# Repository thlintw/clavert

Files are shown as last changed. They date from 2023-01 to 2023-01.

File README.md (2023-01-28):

# Clavert Keyboard

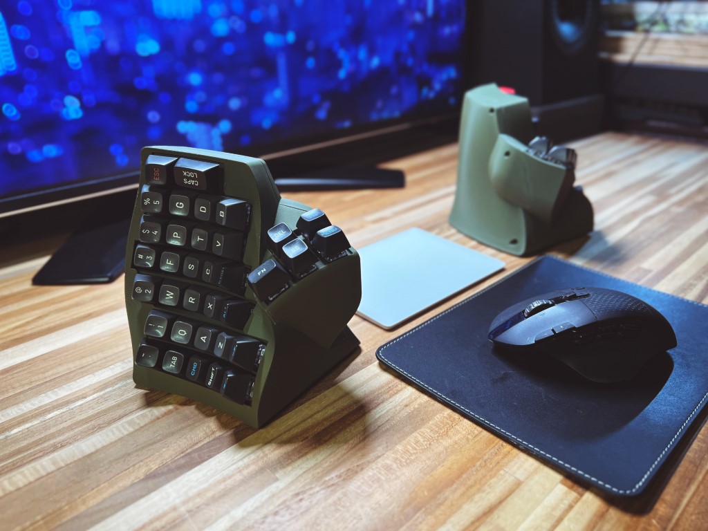
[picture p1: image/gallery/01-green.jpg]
beauty shot


Clavier, vertical.

It's a (pair of?) ZMK powered wireless ergonomic split keyboard.

## Suggested Materials

Below are some of the more important materials for the build. Misc materials not listed.

- MX compatible switches * 70
- Kailh hotswap sockets * 70
- 1N4148 diodes * 70
- EVQWGD001 encoder * 1
- 18650 battery * 2
- nice!nano v2 * 2
- M3*4 heat set inserts * 16
- M3*6 flat head hex screw * 16 (or philips, I used hex because I have them lying around)

This board only uses 1u keycaps because
1. It's really hard to find keycap sets that come with enough 1.5u or 1.25u keys.
2. Thanks to the rise of popularity of ortholinear keyboards it's relatively easy to find good ortho sets and they usually comes with many extra/novelty caps.
3. Your milage may vary but I personally don't think >1u modifiers are necessary.

## Printing the case

Download the STL files from `stl` directory.

The case consists of two halves and a battery holder. They should be printed with the 'inside' facing build plate and with supports. 

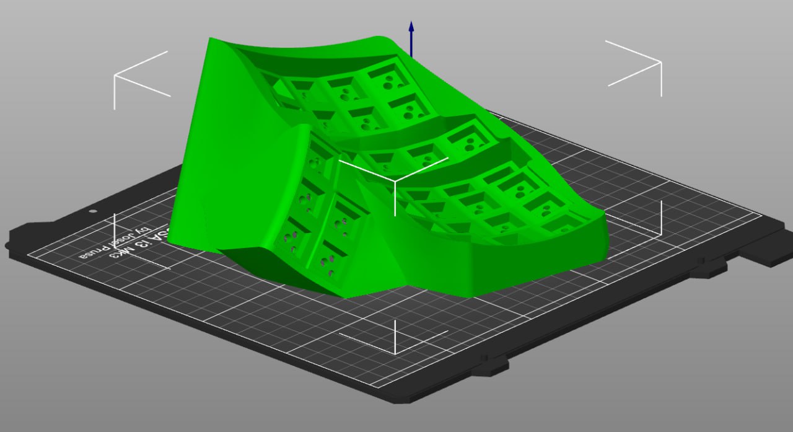
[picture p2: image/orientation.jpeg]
print orientation


Currently there's no cutout for physical reset buttons and power switches because ZMK supports sending reset/bootloader signal with key press. The left side face half comes in two versions, with or without encoder. Only left side because as of writing of this readme ZMK only supports encoders on the central side. The halves and battery holders are assembled with heat set inserts and screws.

**DO NOT** mirror face half and print them because you will mirror the hotswap socket holes too. The back halves are fine.

#### Print setting suggestions

There are a lot of steep overhangs in the lower layers due to the print orientation. If your slicer supports it, it's better to print outer walls first to prevent warping which might result in small details in lower layers getting knocked off.  ("External pemimeters first" for Slic3r and forks and "Wall Ordering -> Outside to Inside" for Cura)

It's best to put supprot inhibitors to the outside of the case or dial down the overhang threshold since these slopes should be printed fine without supports.

## Wiring

I don't know how to design a PCB so this is a hand wired build(lame I know). It's basically a Redox layout with an encoder. Diagram for left hand side below. 

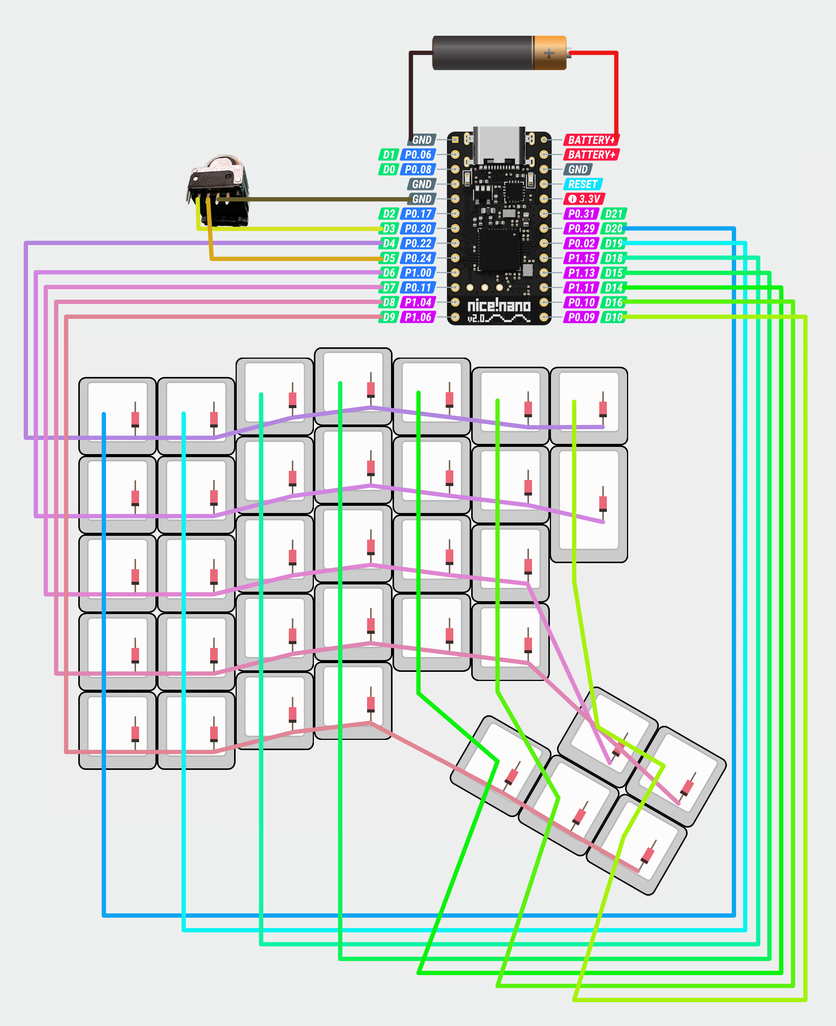
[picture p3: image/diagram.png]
diagram


For right hand simply mirror the columns(i.e. wire leftmost column to 20 instead of 10) and ignore the encoder. You can wire a physical reset button to GND and RESET for easy flashing/resetting. 

## Customizing

You might want to make your own keymap instead of using mine(which I guess only make sense to me). You can fork this repository and edit the .keymap file. ZMK utilize Github actions to compile firmwares so upon commit Github will automatically create firmware files with your keymap. You can find it in the actions tab to your repo -> `https://github.com/$your_username/$your_repo_name/actions`

To flash nice!nanos you need only to double click reset(or quickly bridge GND and RESET twice) and it will show up as a flash drive. You can then drop the `.uf2` files that you grabbed from Github to it and it's done.

Please refer to official ZMK documentations for more info.

https://zmk.dev/docs/user-setup

https://zmk.dev/docs/customization

## Credits

- Obviously, the layout and schematics are from [Redox keyboard](https://github.com/mattdibi/redox-keyboard)
- The design is inspired by and derived from [Redox Manuform by Fosk_LL](https://www.thingiverse.com/thing:3503380)
- The 18650 battery holder is modefied from [this design by YXC](https://www.thingiverse.com/thing:2847497)

## Gallery

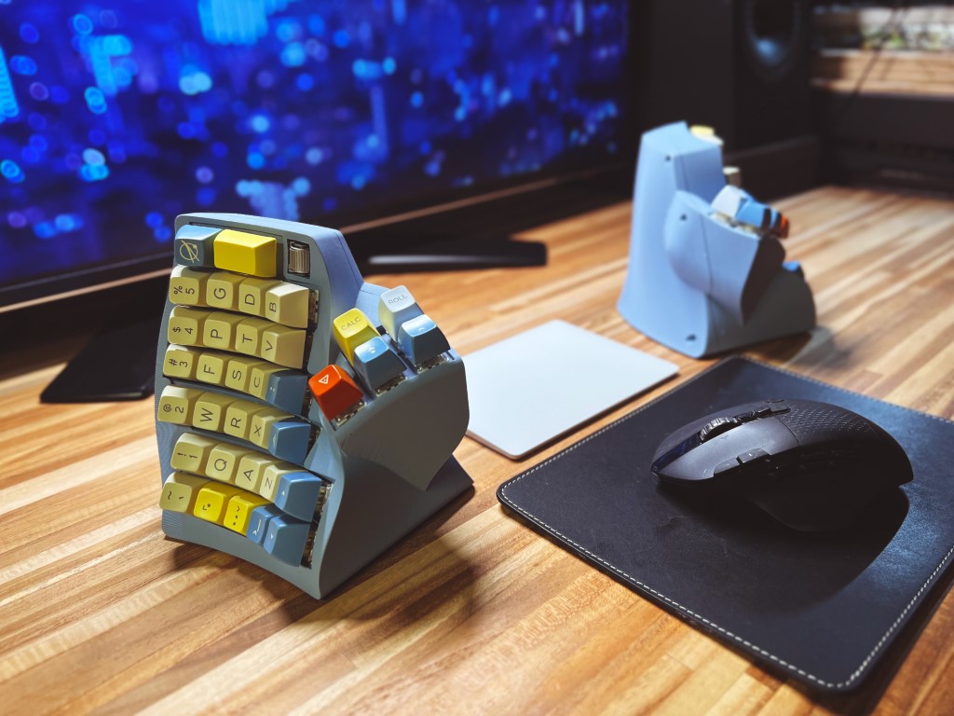
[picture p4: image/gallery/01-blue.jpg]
gallery

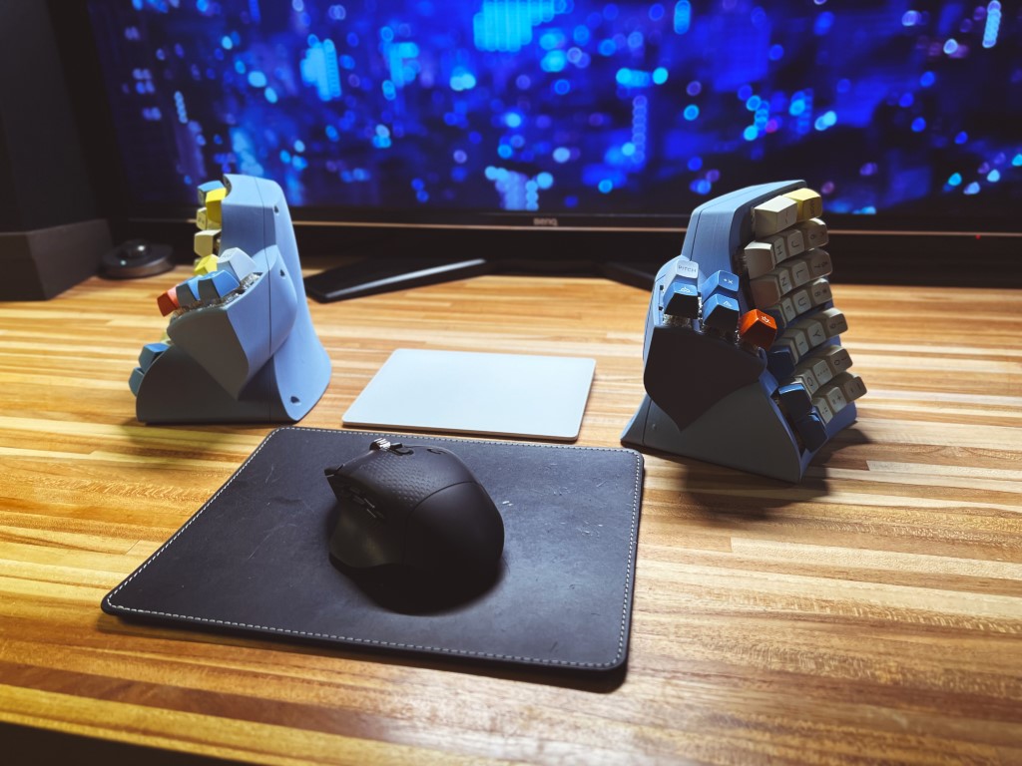
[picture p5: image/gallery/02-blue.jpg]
gallery

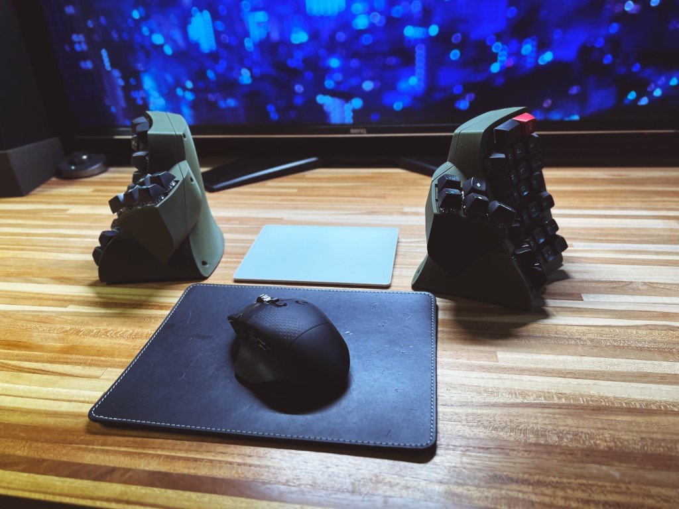
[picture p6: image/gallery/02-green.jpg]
gallery

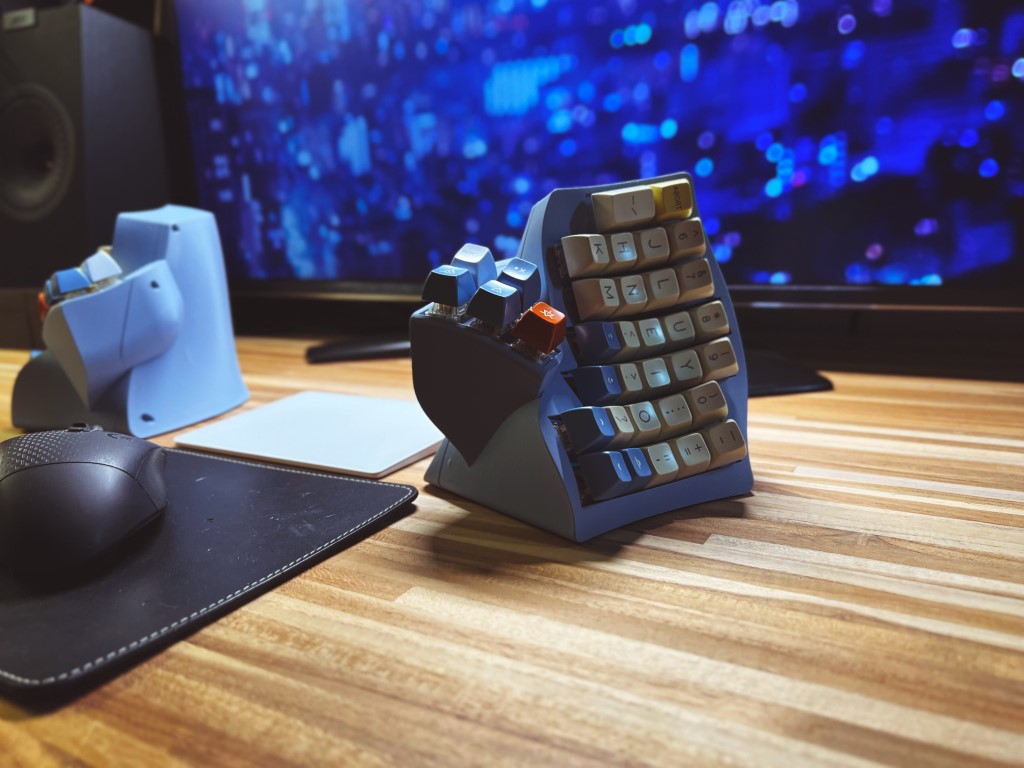
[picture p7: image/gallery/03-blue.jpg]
gallery

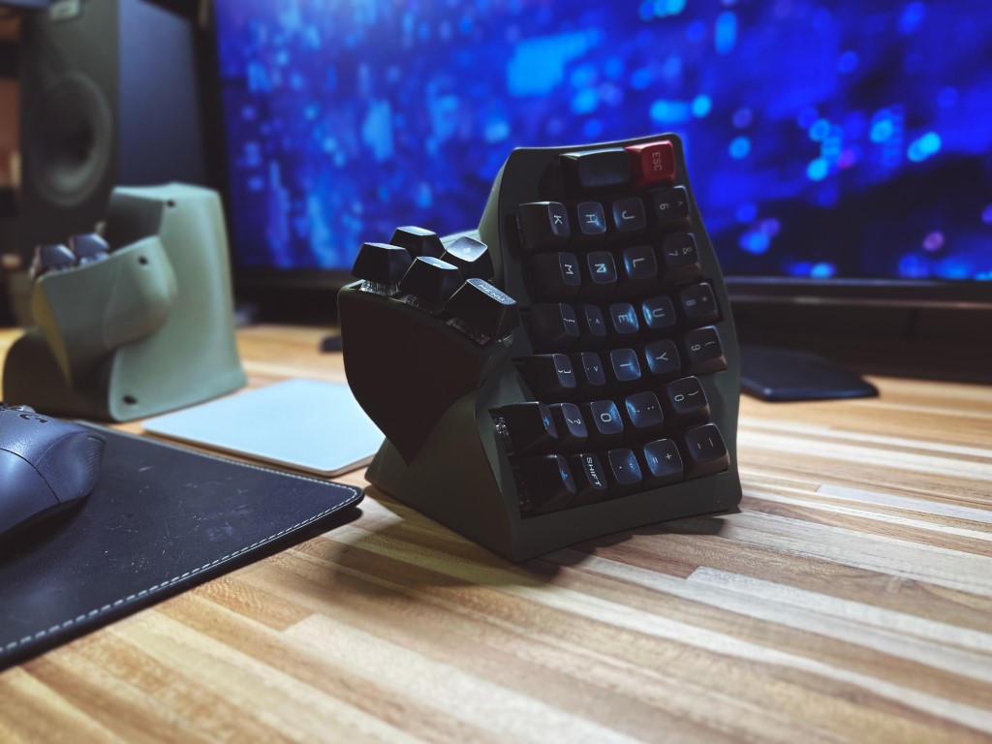
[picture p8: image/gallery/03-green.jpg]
gallery

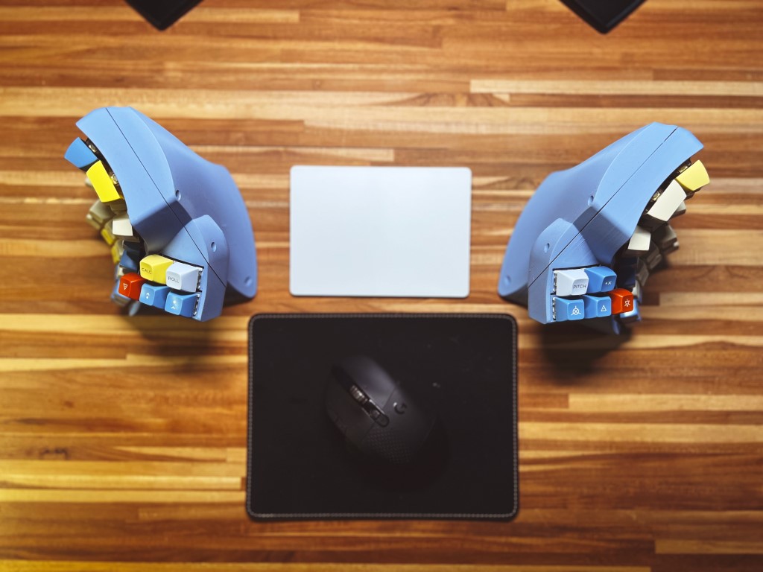
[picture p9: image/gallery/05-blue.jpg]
gallery

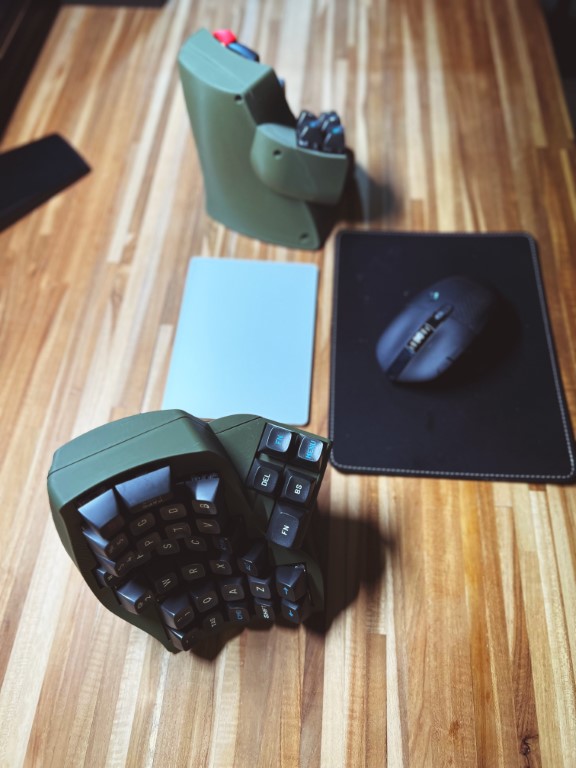
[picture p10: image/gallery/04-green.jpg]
gallery

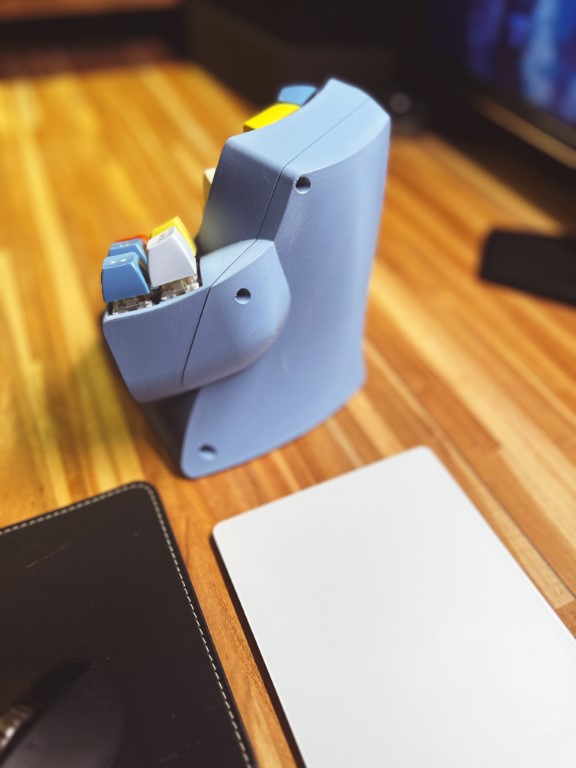
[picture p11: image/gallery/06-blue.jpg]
gallery

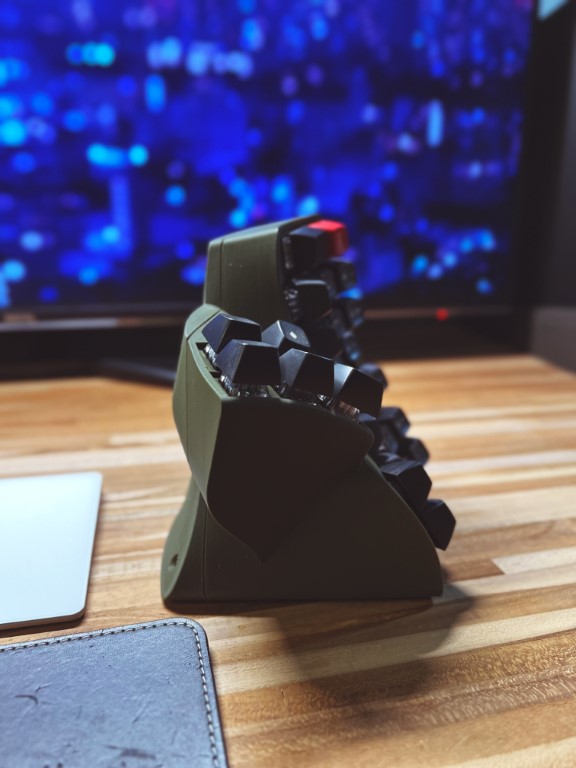
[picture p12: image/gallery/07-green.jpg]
gallery

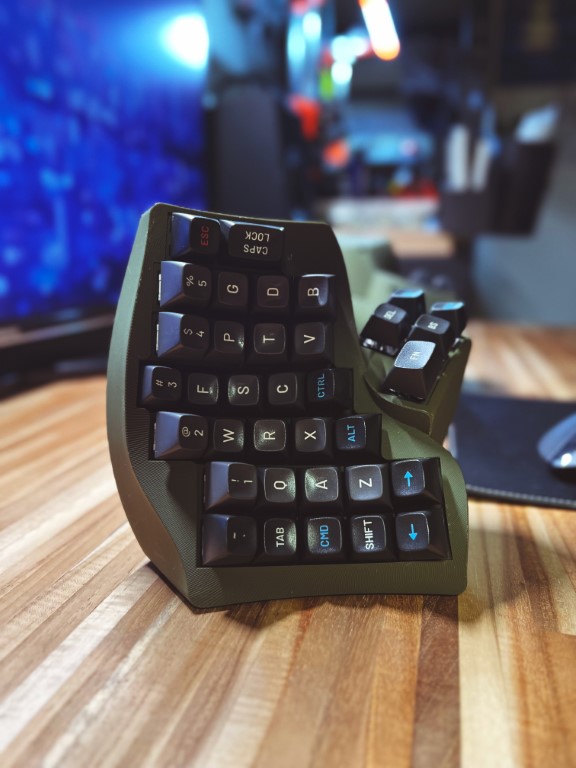
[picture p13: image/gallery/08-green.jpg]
gallery

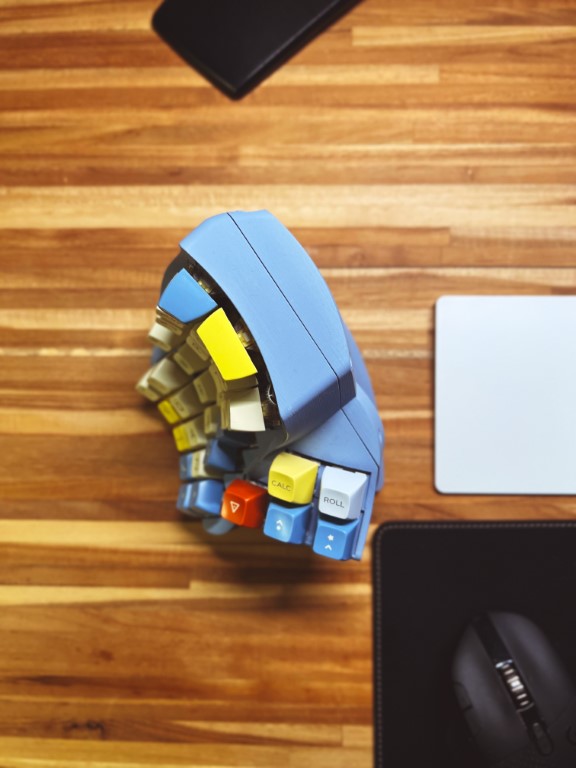
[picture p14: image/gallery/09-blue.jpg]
gallery

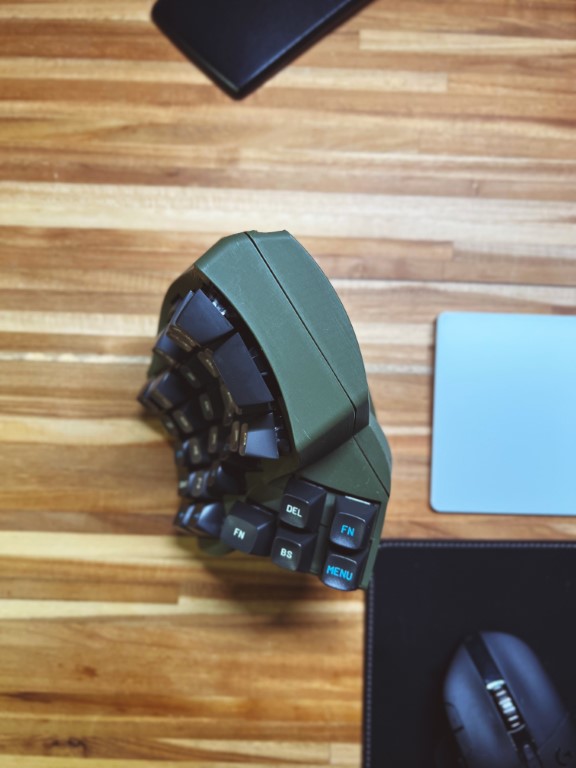
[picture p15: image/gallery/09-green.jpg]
gallery


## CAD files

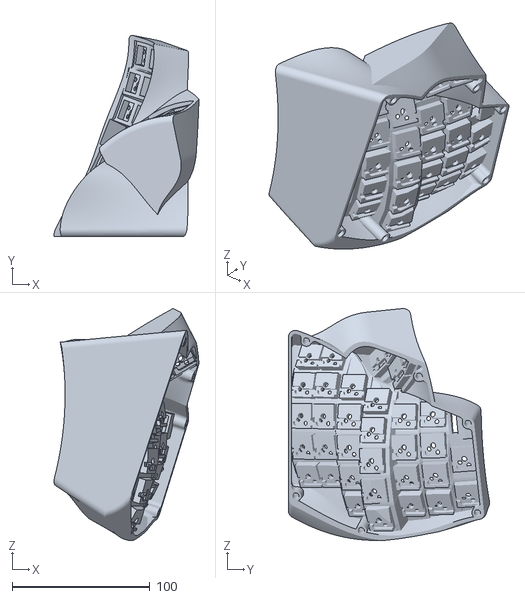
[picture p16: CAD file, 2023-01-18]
stl/face-left-kailh-encoder.STL
105.1 x 146.0 x 168.2

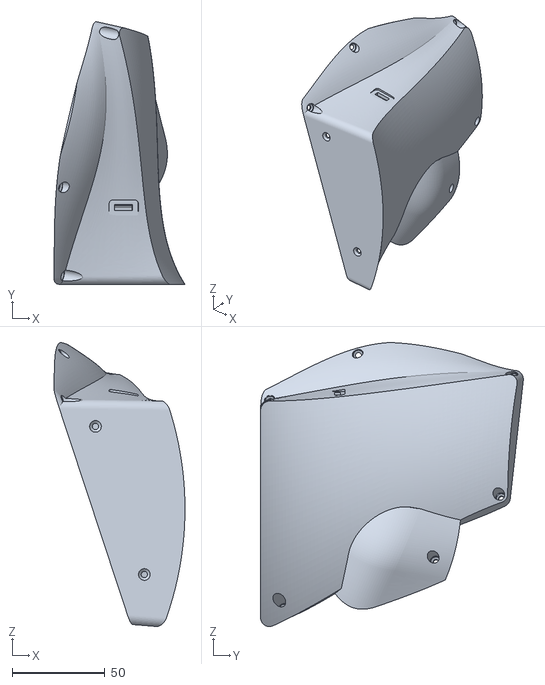
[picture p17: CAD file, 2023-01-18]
stl/back-right.STL
70.8 x 141.9 x 153.4

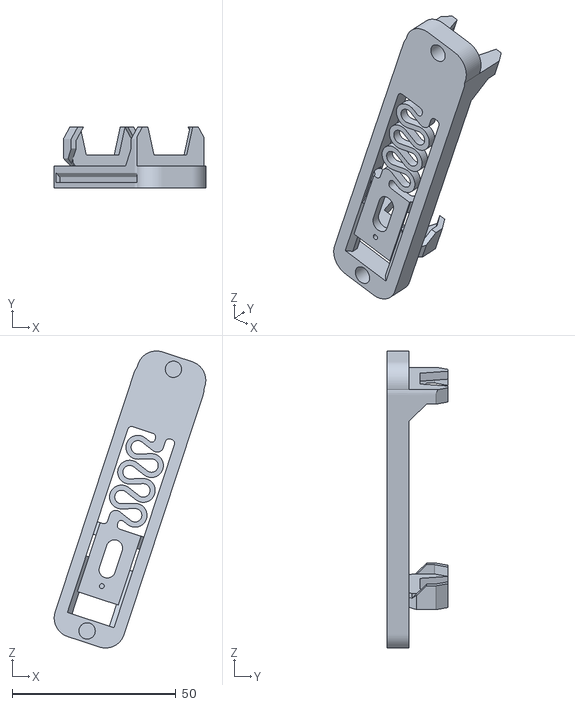
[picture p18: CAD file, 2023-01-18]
stl/battery-holder.STL
46.3 x 18.5 x 90.8

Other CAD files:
stl/face-right-kailh.STL
stl/back-left.STL
stl/face-left-kailh-no-encoder.STL

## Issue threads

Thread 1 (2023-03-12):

Columns in left wiring diagram seem mirrored

BuysDB, 2023-03-12:
Hi, first of thanks a lot for this repo. I never built a keyboard before and I was able to build this set based on your instructions and this went really well, and it is fully working now. Sweet.
There was one small thing I ran into: in the wiring diagram the column connections to the nice!nano are mirrored. (Should be D20 to the leftmost key-column on the diagram).
ps : Maybe you could also add some rubber feet to the BOM?

thlintw, 2023-03-20:
Yeah that seems to be the case sorry about that. I'll fix that soon.

Closed 2023-03-21.

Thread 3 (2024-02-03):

Can't build firmware

klchen0112, 2024-02-03:
All job failed

```log
Run west build -s zmk/app -d "/tmp/tmp.exnzG0O5rc" -b "nice_nano_v2" -- -DZMK_CONFIG=/__w/clavert/clavert/config -DSHIELD="clavert_colemak_dh_right"
+ west build -s zmk/app -d /tmp/tmp.exnzG0O5rc -b nice_nano_v2 -- -DZMK_CONFIG=/__w/clavert/clavert/config -DSHIELD=clavert_colemak_dh_right
-- west build: generating a build system
Loading Zephyr default modules (Zephyr base).
-- Application: /__w/clavert/clavert/zmk/app
-- Found Python3: /usr/bin/python3.8 (found suitable exact version "3.8.10") found components: Interpreter
-- Cache files will be written to: /__w/clavert/clavert/zephyr/.cache
-- Zephyr version: 3.2.0 (/__w/clavert/clavert/zephyr)
-- Found west (found suitable version "1.2.0", minimum required is "0.7.1")
-- Adding ZMK config directory as board root: /__w/clavert/clavert/config
-- Adding /__w/clavert/clavert/config/boards/shields/clavert_colemak_dh
-- ZMK Config directory: /__w/clavert/clavert/config
-- ZMK Config Kconfig: /__w/clavert/clavert/config/clavert_colemak_dh.conf
-- Using keymap file: /__w/clavert/clavert/config/boards/shields/clavert_colemak_dh/clavert_colemak_dh.keymap
-- Board: nice_nano_v2
-- Shield(s): clavert_colemak_dh_right
-- ZEPHYR_TOOLCHAIN_VARIANT not set, trying to locate Zephyr SDK
-- Found host-tools: zephyr 0.[16](https://github.com/klchen0112/clavert/actions/runs/7768198386/job/21185860219#step:11:17).3 (/opt/zephyr-sdk-0.16.3)
-- Found toolchain: zephyr 0.16.3 (/opt/zephyr-sdk-0.16.3)
-- Found Dtc: /opt/zephyr-sdk-0.16.3/sysroots/x86_64-pokysdk-linux/usr/bin/dtc (found suitable version "1.6.0", minimum required is "1.4.6")
-- Found BOARD.dts: /__w/clavert/clavert/zmk/app/boards/arm/nice_nano/nice_nano_v2.dts
-- Found devicetree overlay: /__w/clavert/clavert/config/boards/shields/clavert_colemak_dh/clavert_colemak_dh_right.overlay
-- Found devicetree overlay: /__w/clavert/clavert/config/boards/shields/clavert_colemak_dh/clavert_colemak_dh.keymap
devicetree error: /keymap/fn_layer: undefined node label 'reset'
CMake Error at /__w/clavert/clavert/zephyr/cmake/modules/dts.cmake:[23](https://github.com/klchen0112/clavert/actions/runs/7768198386/job/21185860219#step:11:24)0 (message):
  gen_defines.py failed with return code: 1
Call Stack (most recent call first):
  /__w/clavert/clavert/zephyr/cmake/modules/zephyr_default.cmake:108 (include)
  /__w/clavert/clavert/zephyr/share/zephyr-package/cmake/ZephyrConfig.cmake:66 (include)
  /__w/clavert/clavert/zephyr/share/zephyr-package/cmake/ZephyrConfig.cmake:92 (include_boilerplate)
  CMakeLists.txt:8 (find_package)
-- In: /tmp/tmp.exnzG0O5rc/zephyr, command: /usr/bin/python3.8;/__w/clavert/clavert/zephyr/scripts/dts/gen_defines.py;--dts;/tmp/tmp.exnzG0O5rc/zephyr/zephyr.dts.pre;--dtc-flags;'';--bindings-dirs;/__w/clavert/clavert/zmk/app/module/dts/bindings;/__w/clavert/clavert/zmk/app/dts/bindings;/__w/clavert/clavert/zephyr/dts/bindings;--header-out;/tmp/tmp.exnzG0O5rc/zephyr/include/generated/devicetree_generated.h.new;--dts-out;/tmp/tmp.exnzG0O5rc/zephyr/zephyr.dts.new;--edt-pickle-out;/tmp/tmp.exnzG0O5rc/zephyr/edt.pickle;--vendor-prefixes;/__w/clavert/clavert/zmk/app/dts/bindings/vendor-prefixes.txt;--vendor-prefixes;/__w/clavert/clavert/zephyr/dts/bindings/vendor-prefixes.txt
-- Configuring incomplete, errors occurred!

FATAL ERROR: command exited with status 1: /usr/local/bin/cmake -DWEST_PYTHON=/usr/bin/python3 -B/tmp/tmp.exnzG0O5rc -GNinja -DBOARD=nice_nano_v2 -DZMK_CONFIG=/__w/clavert/clavert/config -DSHIELD=clavert_colemak_dh_right -S/__w/clavert/clavert/zmk/app
Error: Process completed with exit code 1.
```

klchen0112, 2024-02-12:
I fixed it by replacing `reset` with `sys_reset`

Closed 2024-04-25.

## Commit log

2023-01-18 added STL files
    [back-left.STL, back-right.STL, battery-holder.STL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]
2025-07-27 test nice_view_gem
    [clavert.kicad_pcb, clavert.kicad_sch, clavert_cols.kicad_pcb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]
